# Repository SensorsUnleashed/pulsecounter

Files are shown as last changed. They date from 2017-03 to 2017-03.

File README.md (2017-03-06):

# Pulse Counter board

Simple mains powered board that will count any pulses applied to the connector.

RJ45 Connector Pin-out:
* RJ45 Pin 2 - VCC
* RJ45 Pin 5 - GND
* RJ45 Pin 6 - TTL Data

An example of a sensor that will fit the connector directly, can be found here: [Optical Utility Meter LED Pulse Sensor](https://openenergymonitor.org/emon/opticalpulsesensor)

Below you can see the prototype board.
Relayboard

Relayboard

Relayboard

Relayboard

Relayboard

Relayboard

Relayboard

Relayboard

Relayboard

Relayboard

Relayboard

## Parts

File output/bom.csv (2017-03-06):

Reference | "Quantity" | "Value" | "Footprint" | "Datasheet" | "Characteristics" | "Package ID" | "Supplier" | "Manufacturer Name" | "Manufacturer Part Number" | "Supplier Order number" | "Notes" | "Description"
C1 | 1 | 100nF | Capacitors_SMD:C_0805 |  | 25 V, X7R | 0805 | digi key | AVX Corporation | 08053C104KAT2A | 478-3755-1-ND
C2 | 1 | 22uF | Capacitors_SMD:C_0805 | http://datasheets.avx.com/F98.pdf | Tantalum, ESR 4Ohm, 10V, 20% | 0805 | Digikey | AVX Corporation | F981A226MSA | 478-8649-1-ND
IC1 | 1 | AT24C256C-SSHL-T | Housings_SOIC:SOIC-8_3.9x4.9mm_Pitch1.27mm | http://www.atmel.com/images/atmel-8568-seeprom-at24c256c-datasheet.pdf | 256K (32K x 8) eeprom, i2c | 8-SOIC | Aliexpress |  |  | https://www.aliexpress.com/item/Free-shipping-10pcs-lot-AT24C256C-SSHL-T-EEPROM-serial-AT24C256C-screen-2ECL-original-authentic/32699367011.html
J1 | 1 | RJ45 | Connect:RJ45_8 |  |  |  |  | Optical Utility Meter LED Pulse Sensor |  |  | https://openenergymonitor.org/emon/opticalpulsesensor
P1 | 1 | Supply | Connect:AK300-2
P2 | 1 | HLK-PM01 | SensorsUnleashed:HLK-PM01 | https://www.aliexpress.com/item/5pcs-TSP-05-replace-HLK-PM01-AC-DC-220V-to-5V-mini-power-supply-module-intelligent/32409558042.html | 100-240VAC in, 5VDC/3W out |  | Aliexpress |  |  |  | Meets CE and UL; written, but not proven!
P3 | 1 | Sensors Unleashed Radio | SensorsUnleashed:zb3219PA_radio
Q3 | 1 | BC849 | TO_SOT_Packages_SMD:SOT-23 | http://www.mccsemi.com/up_pdf/BC846A-BC849C(SOT-23).pdf |  | SOT23 | Digikey | Micro Commercial Co | BC849C-TP | BC849C-TPMSCT-ND |  | TRANS NPN 30V 0.1A
R5, R8 | 2 | 10k | Resistors_SMD:R_0805
U1 | 1 | AMS1117 | TO_SOT_Packages_SMD:SOT-223 |  | Fixed 3.3V, 1A | SOT-223 |  | Advanced Monolithic Systems | AMS1117-3.3

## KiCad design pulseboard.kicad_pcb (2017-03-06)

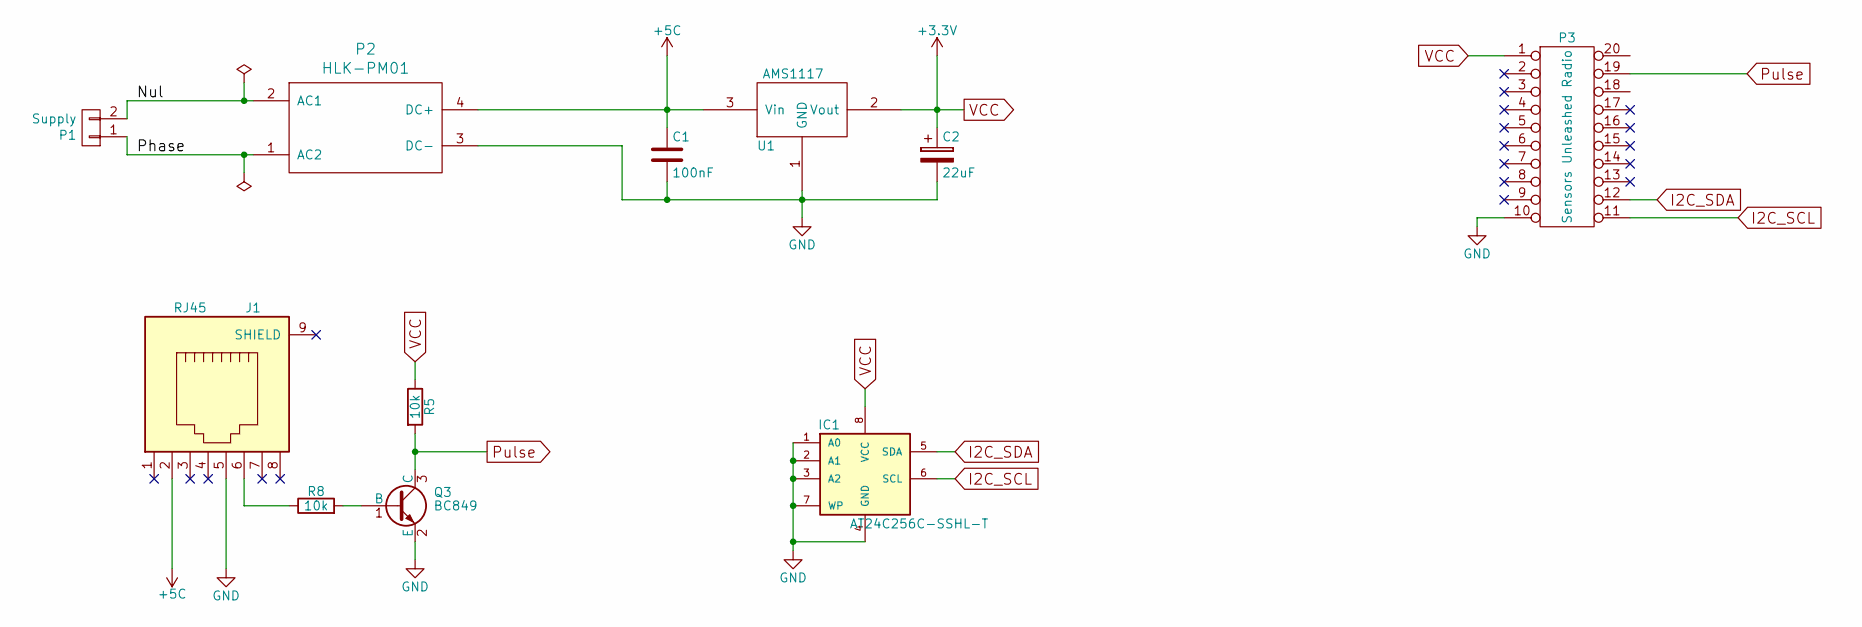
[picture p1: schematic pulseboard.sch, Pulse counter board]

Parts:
C1: 100nF; C_0805; Manufacturer Part Number 08053C104KAT2A
C2: 22uF; C_0805; Manufacturer Part Number F981A226MSA
IC1: AT24C256C-SSHL-T; SOIC-8_3.9x4.9mm_Pitch1.27mm
J1: RJ45; RJ45_8
P1: Supply; AK300-2
P2: HLK-PM01
P3: Sensors Unleashed Radio; zb3219PA_radio
Q3: BC849; SOT-23; Manufacturer Part Number BC849C-TP
R5, R8: 10k; R_0805
U1: AMS1117; SOT-223; Manufacturer Part Number AMS1117-3.3

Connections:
+5C: C1.1, J1.2, P2.4 (DC+), U1.3 (Vin)
/Nul: P1.2, P2.2 (AC1)
/Phase: P1.1, P2.1 (AC2)
GND: C1.2, C2.2, IC1.1 (A0), IC1.2 (A1), IC1.3 (A2), IC1.4 (GND), IC1.7 (WP), J1.5, P2.3 (DC-), P3.10, Q3.2 (E), U1.1 (GND)
I2C_SCL: IC1.6 (SCL), P3.11
I2C_SDA: IC1.5 (SDA), P3.12
unnamed: J1.6, R8.1
unnamed: Q3.1 (B), R8.2
Pulse: P3.19, Q3.3 (C), R5.2
VCC: C2.1, IC1.8 (VCC), P3.1, R5.1, U1.2 (Vout)

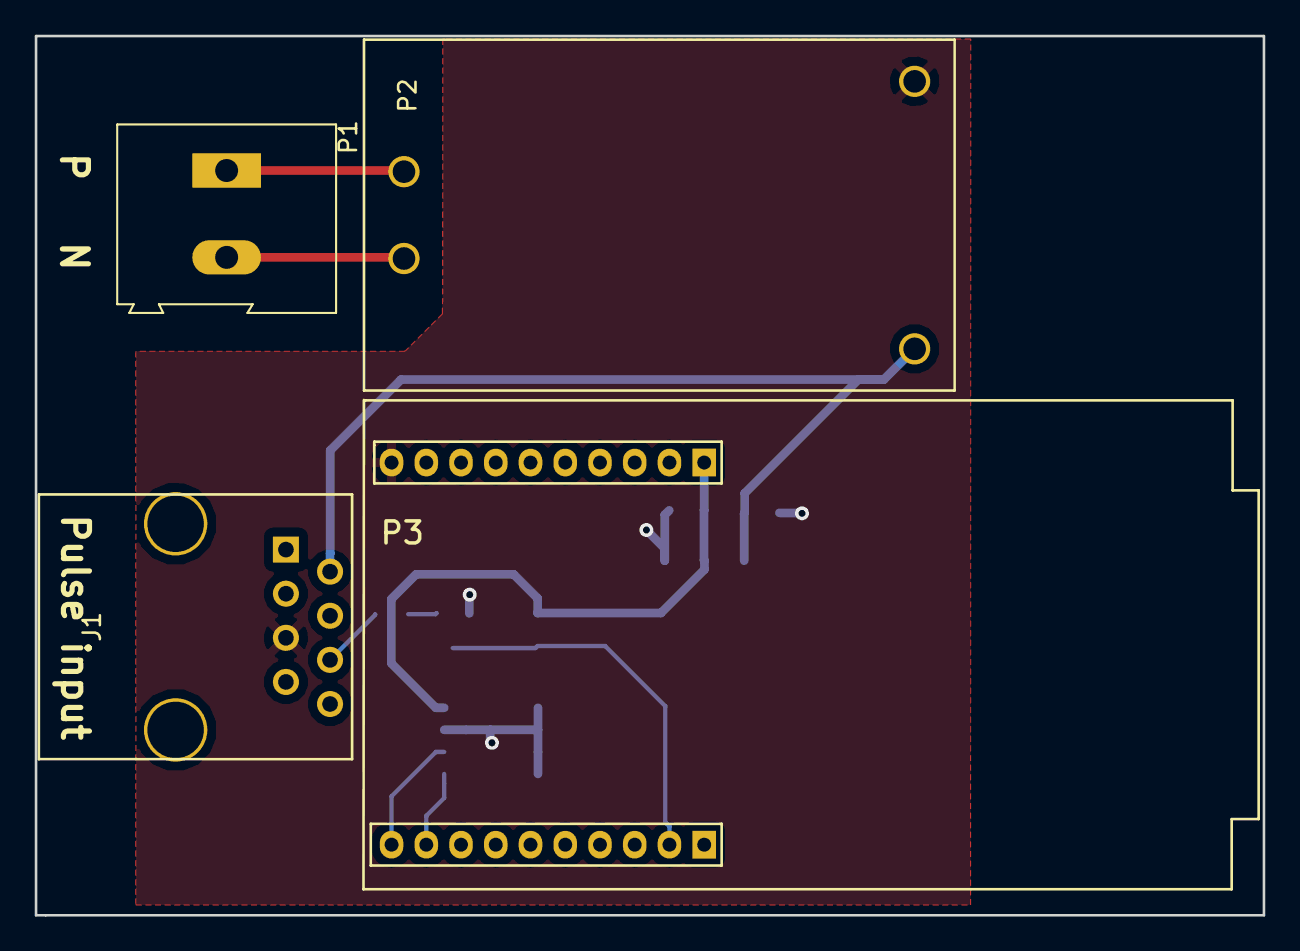
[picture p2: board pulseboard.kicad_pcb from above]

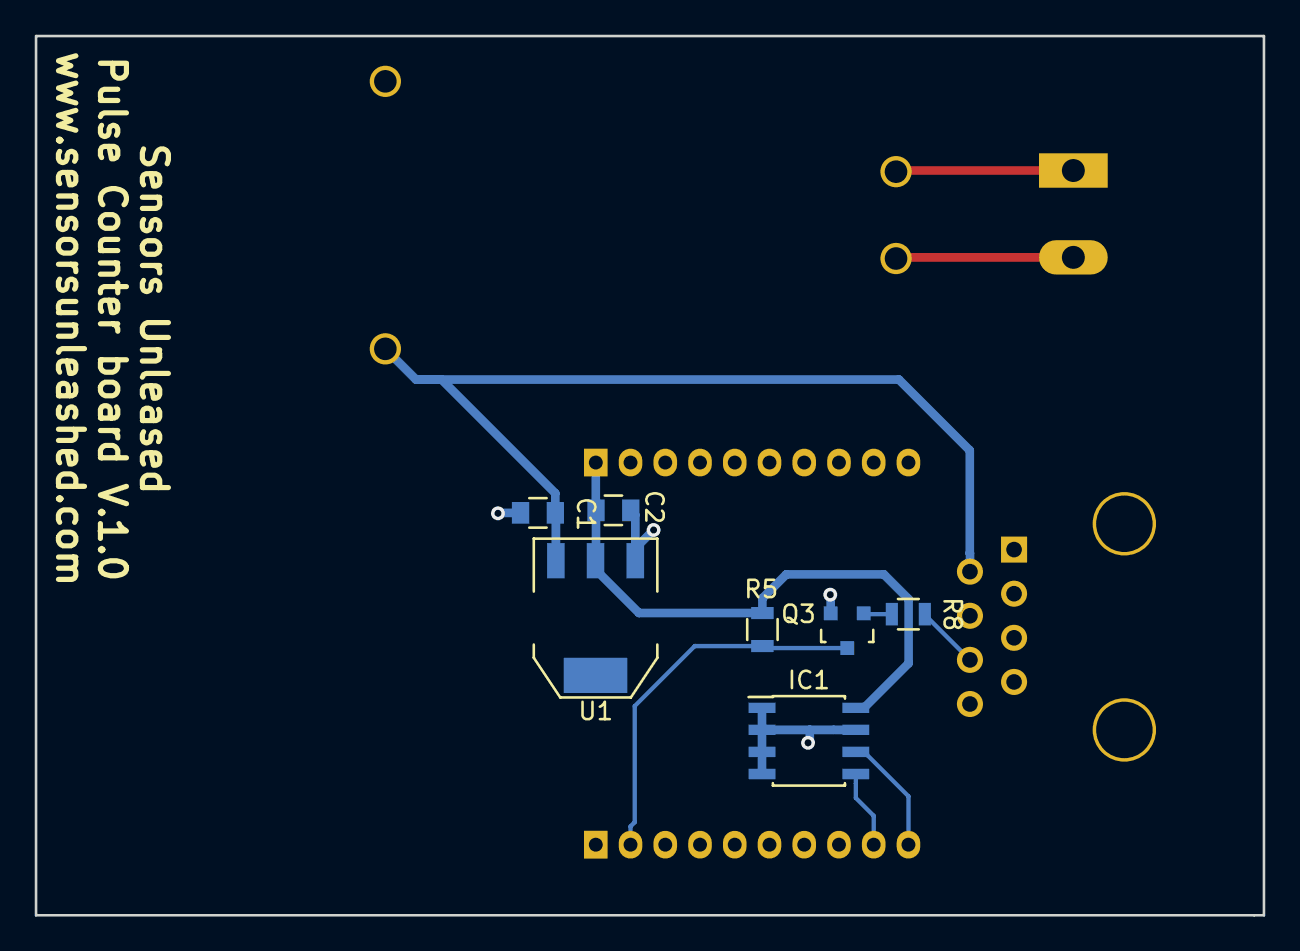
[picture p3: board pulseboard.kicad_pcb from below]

Board: 2 copper layers, 70.7 x 50.6 mm, 11 parts (7 on the bottom side), 10 nets.
